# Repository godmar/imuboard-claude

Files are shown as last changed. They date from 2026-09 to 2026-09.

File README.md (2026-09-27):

# LSM6DSV32X Breakout

A minimal breakout for the ST **LSM6DSV32X** 6-axis IMU (±32 g accel, ±4000 dps gyro).
The circuit follows the mode 1 connection diagram in ST's datasheet (DS13511, Figure 28,
section 7.1).

| | |
|---|---|
| Board size | **20.32 × 10.2 mm**, 2 layers, 1.6 mm FR4. The width is set by the 8-pin header; the height meets JLCPCB's 10 × 10 mm minimum for assembly. |
| Mounting | Two M2 holes (2.2 mm, non-plated) in the top corners, 15.72 mm apart, 1.9 mm from the top edge. There is no copper within 2 mm of each hole, so a screw head or washer can't short anything. |
| Supply | 3.3 V only. VDD and VDDIO are tied together; there is no regulator or level shifter. |
| Interface | I²C / I3C (default) or SPI (3/4-wire) |
| I²C address | **0x6B** (SA0 pulled up by R3). Drive SDO low for 0x6A. |
| Parts | All SMD on top (0402 passives). The header is inserted from the bottom, so its plastic spacer sits under the board. |

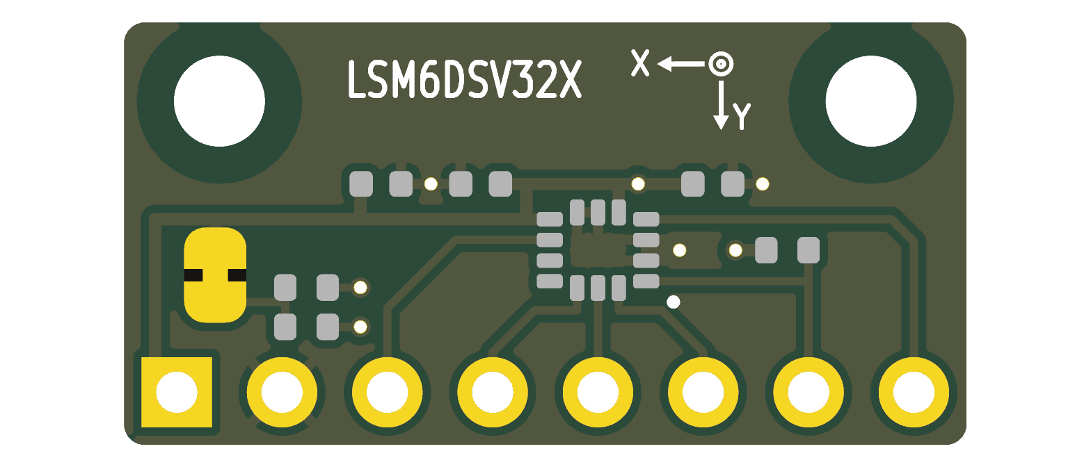
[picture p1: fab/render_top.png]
top

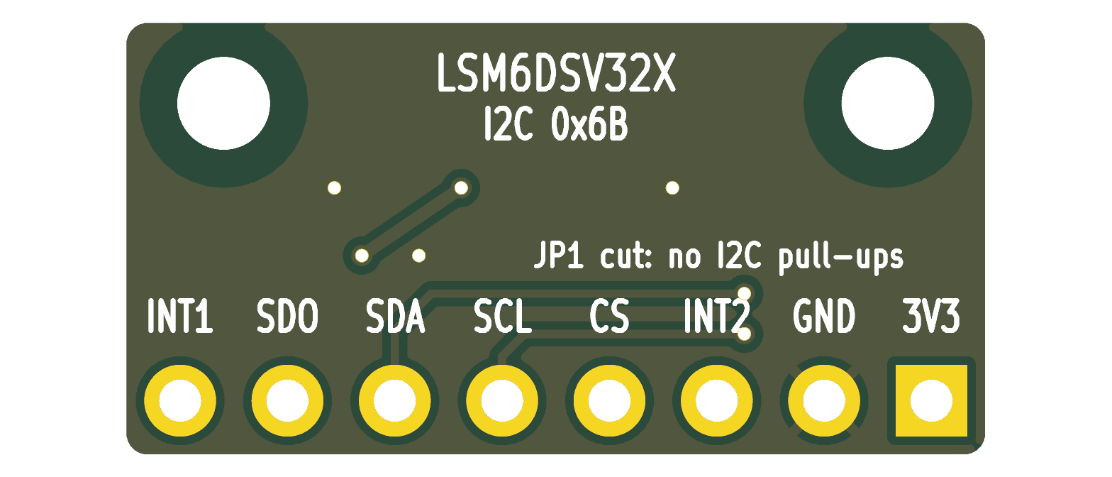
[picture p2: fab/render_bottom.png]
bottom


## Header pinout (J1, 2.54 mm, pin 1 = square pad, left when viewed from the top)

| Pin | 1 | 2 | 3 | 4 | 5 | 6 | 7 | 8 |
|---|---|---|---|---|---|---|---|---|
| Signal | 3V3 | GND | INT2 | CS | SCL / SPC | SDA / SDI | SDO / SA0 | INT1 |

The order follows the ring of IMU pads, so every signal is routed on the top layer without
crossings. The pin names are printed on the back silkscreen.

## Circuit notes

- C1 / C2: 100 nF ceramic on VDDIO and VDD, placed next to the supply pins (datasheet Table 2 note 2, section 7.1).
- C3: 4.7 µF footprint on 3V3; may help if the board is fed through long wires or from a noisy robot supply. 
- R1 / R2: 10 k pull-ups on SCL / SDA (R<sub>pu</sub> = 10 kΩ per Figure 28), enabled through **JP1**, a solder jumper that is bridged by
  default. Cut the trace between its pads to remove the pull-ups, for example when the bus already
  has pull-ups or when using SPI.
- R3: 10 k pull-up on SDO/SA0. The SA0 pin has no internal pull-up by default, so without R3 the
  I²C address would be undefined. In SPI mode SDO actively drives the line, so R3 does no harm.
- CS has an internal pull-up, so the part starts in I²C/I3C mode. Pull CS low to use SPI.
- SDx/SCx (pins 2/3) are tied to GND because the analog hub, Qvar and sensor hub are not used.
  OCS_Aux/SDO_Aux (pins 10/11) are left unconnected. Both follow the datasheet's pin table.
- Axes: U1 is rotated 180° on the board. The front silkscreen arrow shows +X pointing left and
  +Y pointing toward the header; +Z points out of the top face.

## Files

| File | Contents |
|---|---|
| `lsm6dsv32x_breakout.kicad_pro/.kicad_sch/.kicad_pcb` | KiCad 9 project |
| `imuboard.kicad_sym`, `sym-lib-table` | Project symbol library (LSM6DSV32X symbol) |
| `fab/lsm6dsv32x_breakout_gerbers.zip` | Gerbers + Excellon drill files, ready to upload |
| `fab/*_bom.csv`, `fab/*_pos_top.csv` | BOM and top-side pick-and-place file (origin: bottom-left corner) |
| `fab/*_bom_jlcpcb.xlsx`, `fab/*_cpl_jlcpcb.xlsx` (+ `.csv`) | The same in JLCPCB's assembly upload format, matching their sample files (SMD parts only; J1 is fitted by hand) |
| `fab/*_schematic.pdf`, `fab/*_assembly_top.pdf` | Printable schematic and assembly drawing |
| `fab/erc.rpt`, `fab/drc.rpt` | Check reports (0 ERC, 0 DRC, 0 unconnected, 0 schematic-parity issues) |
| `tools/` | Generator scripts that produce the files above |

The design is **generated from scripts**. `tools/design.py` holds the netlist,
`tools/gen_schematic.py` writes the schematic, and `tools/gen_pcb.py` does placement,
routing, the GND pours on both layers, and the silkscreen. To rebuild everything, including
the fab outputs and the checks:

```sh
./tools/make_fab.sh
```

You can also edit the `.kicad_sch` / `.kicad_pcb` files directly in KiCad. Regenerating
overwrites those edits.

## Fabrication rules used

- Clearance 0.15 mm (the LGA's 0.5 mm pitch pads are 0.15 mm apart)
- Tracks 0.2 mm for signals, 0.3 mm for 3V3
- Vias 0.5 mm diameter / 0.3 mm drill, tented
- Copper to board edge 0.25 mm
- Copper keepout of 2 mm radius around each mounting hole

These are within standard JLCPCB/PCBWay 2-layer capabilities. The LGA-14 needs stencil and
reflow (or hot air) assembly.

The library footprints' silkscreen was moved to the Fab layers because the board is too dense
for it. For the same reason the project ignores the "footprint differs from library" DRC check.

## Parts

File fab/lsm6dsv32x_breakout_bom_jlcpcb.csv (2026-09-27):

Comment | Designator | Footprint | JLCPCB Part #（optional）
100nF | C1,C2 | C_0402_1005Metric
4.7uF | C3 | C_0402_1005Metric
10k | R1,R2,R3 | R_0402_1005Metric
LSM6DSV32XTR | U1 | LGA-14_3x2.5mm_P0.5mm_LayoutBorder3x4y

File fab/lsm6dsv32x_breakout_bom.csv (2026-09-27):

Refs | Value | Footprint | MPN | Note | Qty
C1,C2 | 100nF | Capacitor_SMD:C_0402_1005Metric |  | Vdd decoupling,Vdd_IO decoupling | 2
C3 | 4.7uF | Capacitor_SMD:C_0402_1005Metric |  | optional bulk for noisy/long supply wiring, X5R 6.3V+ | 1
J1 | Conn_01x08 | Connector_PinHeader_2.54mm:PinHeader_1x08_P2.54mm_Vertical |  |  | 1
R1-R3 | 10k | Resistor_SMD:R_0402_1005Metric |  | SA0=1 -> I2C addr 0x6B | 3
U1 | LSM6DSV32X | Package_LGA:LGA-14_3x2.5mm_P0.5mm_LayoutBorder3x4y | LSM6DSV32XTR |  | 1

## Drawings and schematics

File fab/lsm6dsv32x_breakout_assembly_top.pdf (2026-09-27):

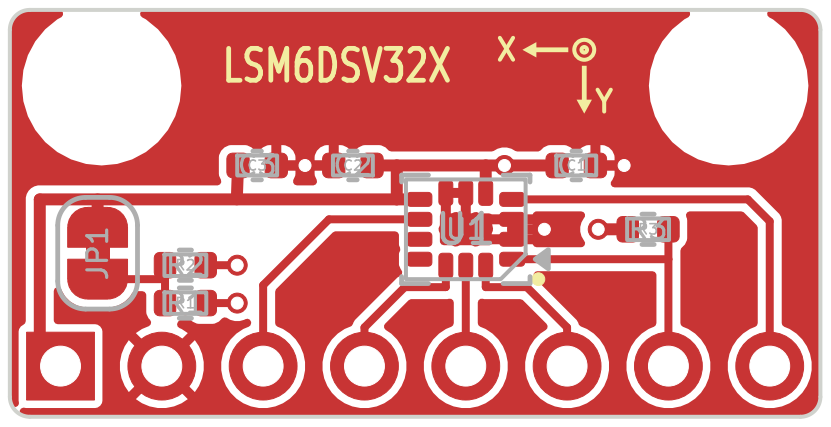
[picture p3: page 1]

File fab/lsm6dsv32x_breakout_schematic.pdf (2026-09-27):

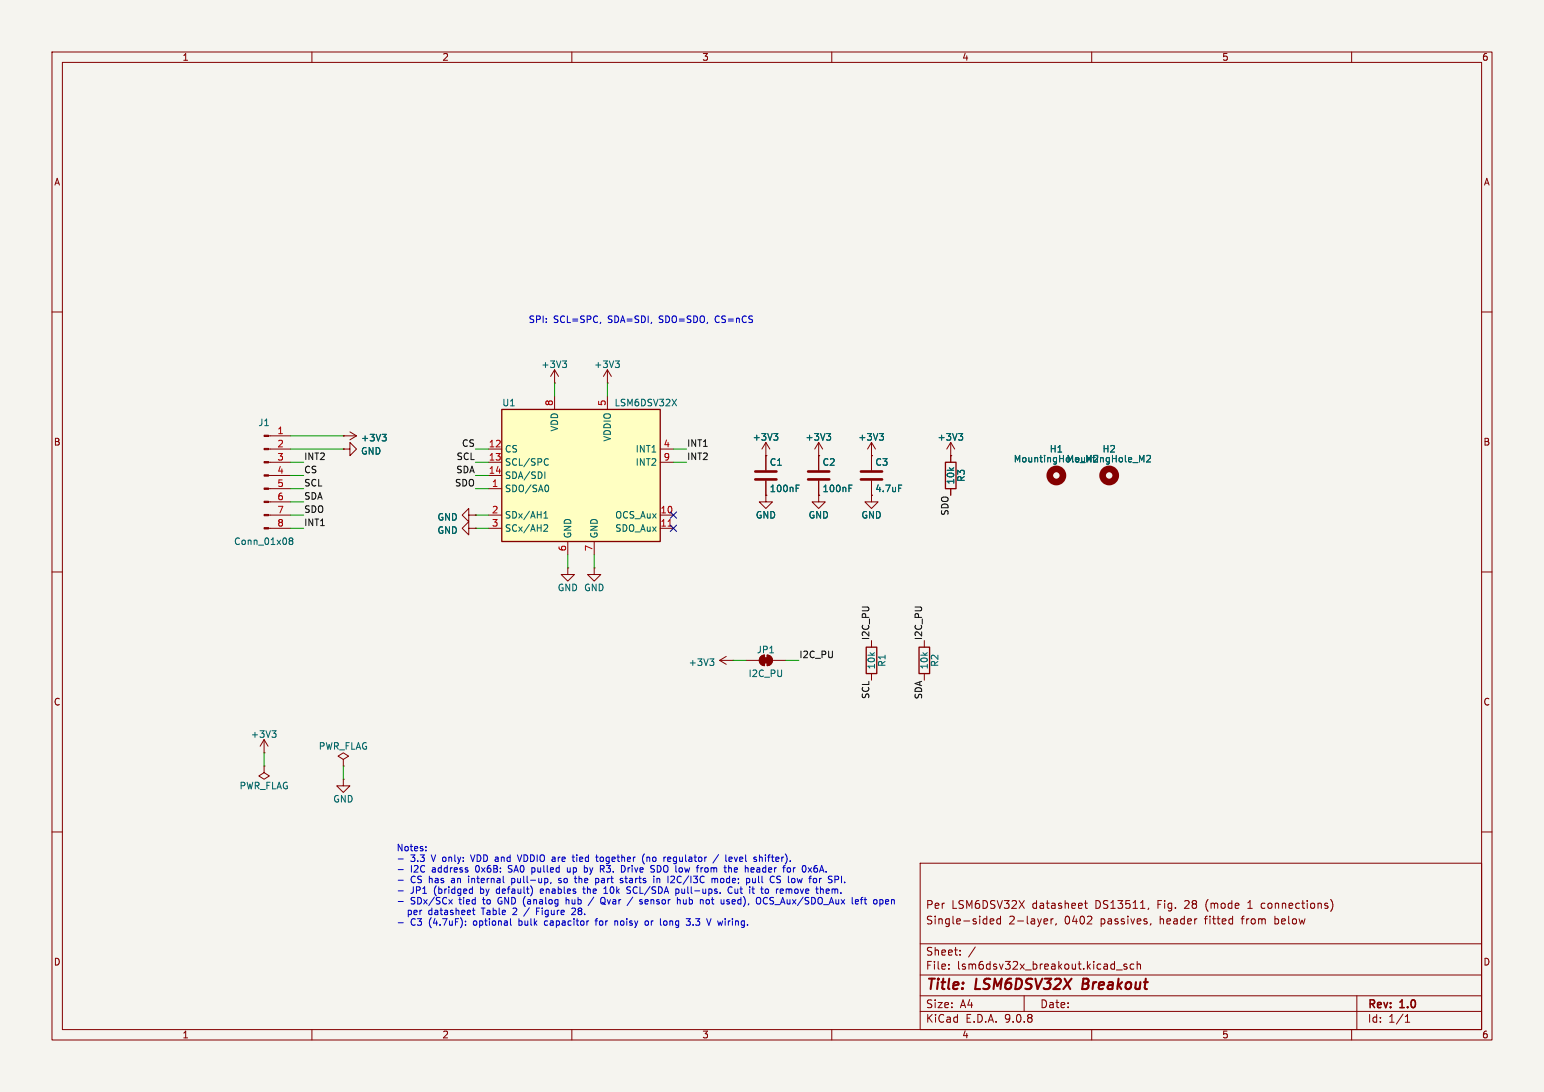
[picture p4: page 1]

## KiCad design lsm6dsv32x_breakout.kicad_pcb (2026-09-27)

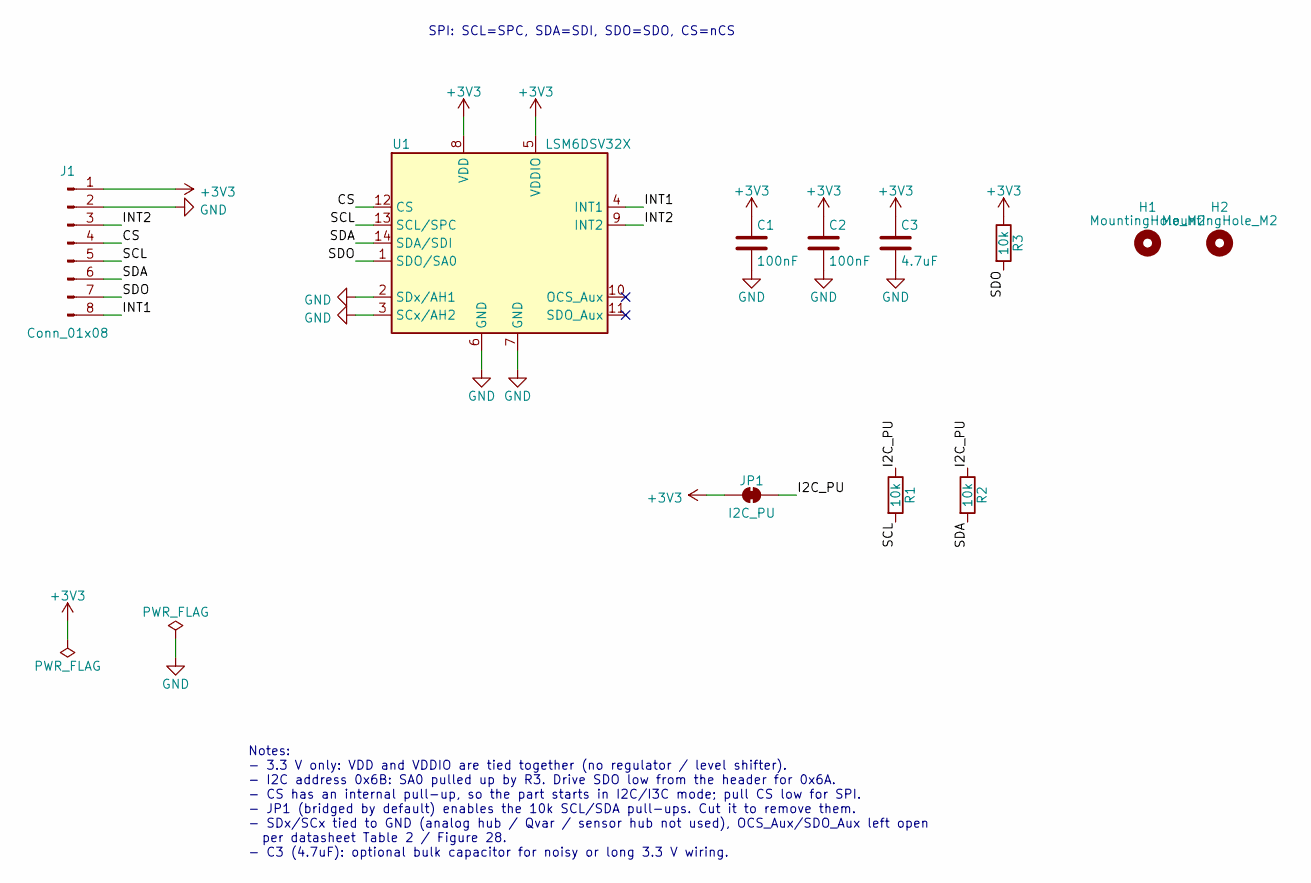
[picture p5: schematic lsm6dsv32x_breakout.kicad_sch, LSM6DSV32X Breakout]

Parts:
C1, C2: 100nF; C_0402_1005Metric
C3: 4.7uF; C_0402_1005Metric
H1, H2: MountingHole_M2; MountingHole_2.2mm_M2
J1: Conn_01x08; PinHeader_1x08_P2.54mm_Vertical
JP1: I2C_PU; SolderJumper-2_P1.3mm_Bridged_RoundedPad1.0x1.5mm
R1, R2, R3: 10k; R_0402_1005Metric
U1: LSM6DSV32X; LGA-14_3x2.5mm_P0.5mm_LayoutBorder3x4y; MPN LSM6DSV32XTR

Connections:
+3V3: C1.1, C2.1, C3.1, J1.1, JP1.1 (A), R3.1, U1.5 (VDDIO), U1.8 (VDD)
/CS: J1.4, U1.12 (CS)
/I2C_PU: JP1.2 (B), R1.1, R2.1
/INT1: J1.8, U1.4 (INT1)
/INT2: J1.3, U1.9 (INT2)
/SCL: J1.5, R1.2, U1.13 (SCL/SPC)
/SDA: J1.6, R2.2, U1.14 (SDA/SDI)
/SDO: J1.7, R3.2, U1.1 (SDO/SA0)
GND: C1.2, C2.2, C3.2, J1.2, U1.2 (SDx/AH1), U1.3 (SCx/AH2), U1.6 (GND), U1.7 (GND)

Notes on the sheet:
Notes: - 3.3 V only: VDD and VDDIO are tied together (no regulator / level shifter). - I2C address 0x6B: SA0 pulled up by R3. Drive SDO low from the header for 0x6A. - CS has an internal pull-up, so the part starts in I2C/I3C mode; pull CS low for SPI. - JP1 (bridged by default) enables the 10k SCL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
SPI: SCL=SPC, SDA=SDI, SDO=SDO, CS=nCS

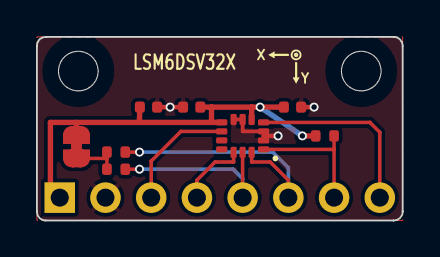
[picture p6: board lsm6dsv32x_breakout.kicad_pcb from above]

Board: 2 copper layers, 20.3 x 10.2 mm, 11 parts (1 on the bottom side), 9 nets.

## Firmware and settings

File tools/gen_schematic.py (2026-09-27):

#!/usr/bin/env python3
"""Generate the project symbol library, sym-lib-table and the schematic.

Run from anywhere:  python3 tools/gen_schematic.py
"""
import json
import math
import os
import uuid

from design import COMPONENTS, PROJECT, TITLE, REV, POWER_NETS, NOT_IN_BOM, DNP
from sexpr import QStr as Q, parse, dump, find, find_all

ROOT = os.path.dirname(os.path.dirname(os.path.abspath(__file__)))
KICAD_SYM = '/usr/share/kicad/symbols'
NS = uuid.UUID('6f1c1d52-4c1e-4f0b-9d3e-3f6b1a9e0d11')


def uid(*parts):
    """Deterministic UUIDs so regenerating keeps schematic<->PCB links."""
    return str(uuid.uuid5(NS, '/'.join(parts)))


def font(size=1.27):
    return ['font', ['size', size, size]]


def effects(justify=None, hide=False, size=1.27):
    e = ['effects', font(size)]
    if justify:
        e.append(['justify'] + justify.split())
    if hide:
        e.append(['hide', 'yes'])
    return e


# ---------------------------------------------------------------- symbol lib
def lsm6dsv32x_symbol(name='LSM6DSV32X'):
    def pin(typ, num, pname, x, y, ang):
        return ['pin', typ, 'line', ['at', x, y, ang], ['length', 2.54],
                ['name', Q(pname), effects()], ['number', Q(num), effects()]]

    pins = [
        pin('input', '12', 'CS', -17.78, 5.08, 0),
        pin('input', '13', 'SCL/SPC', -17.78, 2.54, 0),
        pin('bidirectional', '14', 'SDA/SDI', -17.78, 0, 0),
        pin('bidirectional', '1', 'SDO/SA0', -17.78, -2.54, 0),
        pin('passive', '2', 'SDx/AH1', -17.78, -7.62, 0),
        pin('passive', '3', 'SCx/AH2', -17.78, -10.16, 0),
        pin('output', '4', 'INT1', 17.78, 5.08, 180),
        pin('output', '9', 'INT2', 17.78, 2.54, 180),
        pin('passive', '10', 'OCS_Aux', 17.78, -7.62, 180),
        pin('passive', '11', 'SDO_Aux', 17.78, -10.16, 180),
        pin('power_in', '8', 'VDD', -5.08, 15.24, 270),
        pin('power_in', '5', 'VDDIO', 5.08, 15.24, 270),
        pin('power_in', '6', 'GND', -2.54, -15.24, 90),
        pin('power_in', '7', 'GND', 2.54, -15.24, 90),
    ]

    def prop(k, v, x, y, justify=None, hide=False):
        return ['property', Q(k), Q(v), ['at', x, y, 0], effects(justify, hide)]

    return ['symbol', Q(name),
            ['exclude_from_sim', 'no'], ['in_bom', 'yes'], ['on_board', 'yes'],
            prop('Reference', 'U', -15.24, 13.97, 'left'),
            prop('Value', name, 6.35, 13.97, 'left'),
            prop('Footprint', 'Package_LGA:LGA-14_3x2.5mm_P0.5mm_LayoutBorder3x4y',
                 0, -17.78, hide=True),
            prop('Datasheet', 'https://www.st.com/resource/en/datasheet/lsm6dsv32x.pdf',
                 0, -20.32, hide=True),
            prop('Description', '6-axis IMU, +-32g accelerometer, +-4000dps gyroscope, '
                 'I2C/I3C/SPI, 1.71V to 3.6V, LGA-14L 2.5x3mm', 0, 0, hide=True),
            prop('ki_keywords', 'IMU accelerometer gyroscope MEMS ST', 0, 0, hide=True),
            prop('ki_fp_filters', 'LGA*3x2.5mm*P0.5mm*LayoutBorder3x4y*', 0, 0, hide=True),
            ['symbol', Q(name + '_0_1'),
             ['rectangle', ['start', -15.24, 12.7], ['end', 15.24, -12.7],
              ['stroke', ['width', 0.254], ['type', 'default']],
              ['fill', ['type', 'background']]]],
            ['symbol', Q(name + '_1_1')] + pins]


def write_symbol_lib():
    lib = ['kicad_symbol_lib', ['version', 20241209], ['generator', Q('imuboard_gen')],
           ['generator_version', Q('9.0')], lsm6dsv32x_symbol()]
    with open(os.path.join(ROOT, 'imuboard.kicad_sym'), 'w') as f:
        f.write(dump(lib) + '\n')
    with open(os.path.join(ROOT, 'sym-lib-table'), 'w') as f:
        f.write('(sym_lib_table\n\t(version 7)\n')
        f.write('\t(lib (name "imuboard")(type "KiCad")(uri "${KIPRJMOD}/imuboard.kicad_sym")'
                '(options "")(descr "LSM6DSV32X breakout project symbols"))\n')
        # Stock libraries too, so the project resolves even without a global table.
        for lib in ('Device', 'power', 'Connector', 'Jumper', 'Mechanical'):
            f.write('\t(lib (name "%s")(type "KiCad")(uri "${KICAD9_SYMBOL_DIR}/%s.kicad_sym")'
                    '(options "")(descr "KiCad stock"))\n' % (lib, lib))
        f.write(')\n')


# ------------------------------------------------------------- lib symbols
_lib_cache = {}


def lib_symbol(lib_id):
    """Return a symbol definition renamed to 'Lib:Name' for lib_symbols."""
    lib, name = lib_id.split(':')
    if lib == 'imuboard':
        sym = lsm6dsv32x_symbol()
    else:
        if lib not in _lib_cache:
            with open(os.path.join(KICAD_SYM, lib + '.kicad_sym')) as f:
                _lib_cache[lib] = parse(f.read())
        sym = next(s for s in find_all(_lib_cache[lib], 'symbol') if s[1] == name)
        assert not find(sym, 'extends'), lib_id
    sym = list(sym)
    sym[1] = Q(lib_id)
    return sym


def sym_pins(sym):
    """{number: (x, y, angle)} in library coordinates (Y up)."""
    out = {}

    def walk(node):
        for x in node:
            if isinstance(x, list) and x:
                if x[0] == 'pin':
                    at = find(x, 'at')
                    out[str(find(x, 'number')[1])] = tuple(float(v) for v in at[1:4])
                else:
                    walk(x)
    walk(sym)
    return out


def xform(dx, dy, rot):
    """Library offset (Y up) -> schematic offset (Y down), rotated CCW by rot."""
    x, y = dx, -dy
    for _ in range(int(rot // 90) % 4):
        x, y = y, -x
    return x, y


def snap(v):
    return round(v / 1.27) * 1.27
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

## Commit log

2026-09-27 initial checkin - all generated by Opus 5.5
    [lsm6dsv32x_breakout-B_Cu.gbl, lsm6dsv32x_breakout-B_Mask.gbs, lsm6dsv32x_breakout-B_Paste.gbp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]
2026-09-27 Enlarge board to 20.32 x 10.2 mm and add two M2 mounting holes
    JLCPCB assembly requires at least 10 x 10 mm. The circuit area moves down
    3.2 mm, and the new top band holds two non-plated M2 holes (H1/H2) with a
    2 mm copper keepout on both layers. The title and axis marker silkscreen
    move into that band.
    Also:
    - schematic note marks C3 as DNP only when it is in design.DNP
    - make_fab.sh aborts if gen_pcb.py fails instead of hiding the error
    - README updated for the new size and the mounting holes
    [lsm6dsv32x_breakout-B_Cu.gbl, lsm6dsv32x_breakout-B_Mask.gbs, lsm6dsv32x_breakout-B_Paste.gbp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]
2026-09-27 Add JLCPCB-format CPL and BOM (xlsx + csv)
    KiCad's position/BOM CSVs are rejected by JLCPCB's assembly upload.
    tools/jlc_files.py converts them to the layouts of JLCPCB's sample files
    (Designator/Mid X/Mid Y/Layer/Rotation for the CPL; Comment/Designator/
    Footprint/JLCPCB Part # for the BOM), SMD parts only since J1 is hand-fitted.
    tools/xlsx.py writes the .xlsx versions without external dependencies.
    make_fab.sh runs the conversion; README lists the new files.
    [lsm6dsv32x_breakout-B_Cu.gbl, lsm6dsv32x_breakout-B_Mask.gbs, lsm6dsv32x_breakout-B_Paste.gbp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]
